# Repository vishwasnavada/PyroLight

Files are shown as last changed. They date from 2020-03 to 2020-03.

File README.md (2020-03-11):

# PyroLight
Automated switch bot for switches using Kemet SS-430 Sensor 

Project Link:
[PyroLight](https://www.hackster.io/vishwasnavada/pyrolight-1d4a31)

##  Initial Protype image
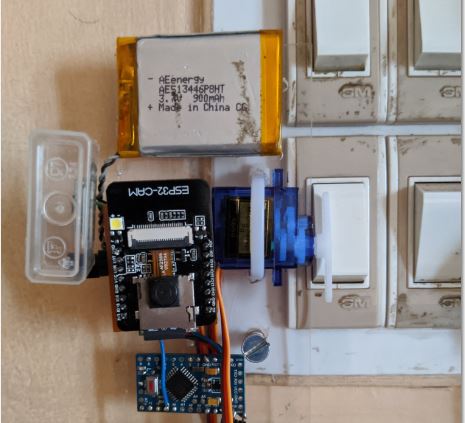
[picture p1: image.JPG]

## Final PCB Version
### Frontside 
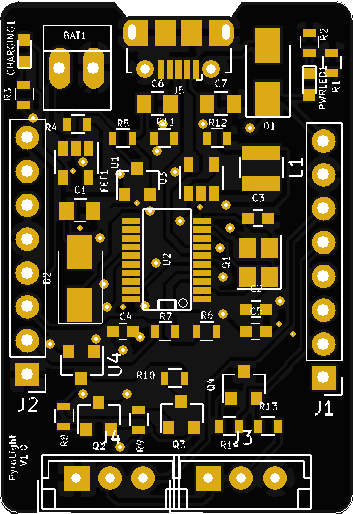
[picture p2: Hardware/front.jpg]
front


### Backside 
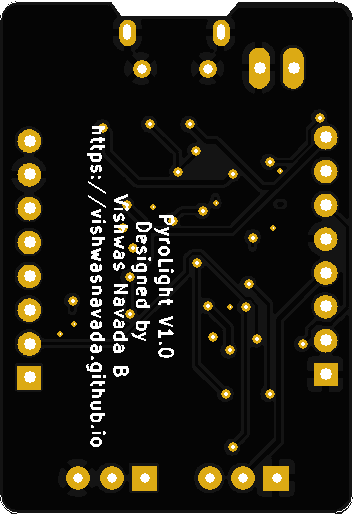
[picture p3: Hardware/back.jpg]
back


### 3D View
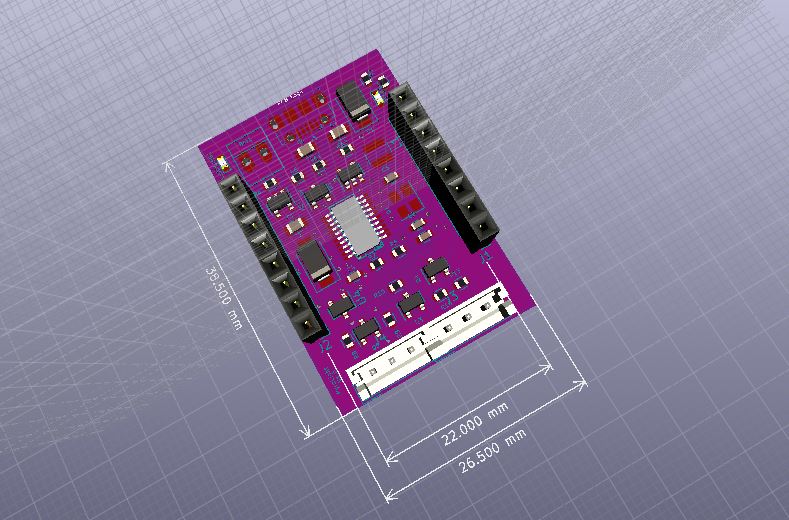
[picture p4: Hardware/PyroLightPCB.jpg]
PyroLightPCB


Here's the video Link:
Watch the video (https://youtu.be/70MHgPO923Y)

I referred schematics from olimex for the esp 32 charging circuit.

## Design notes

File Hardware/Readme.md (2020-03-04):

# Instruction
This folder contains the schematics for the add on board which directly sits on the esp32 Camera board
to program and use it as a normal PyroLight device

## 3D View
PyroLightPCB
### Frontside 
front
### Backside
back

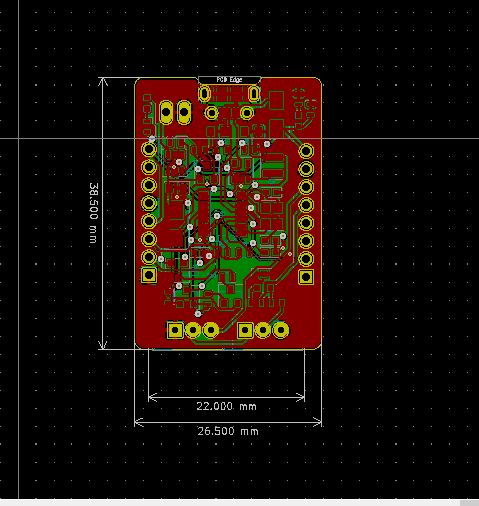
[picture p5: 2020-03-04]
Hardware/PCB.JPG

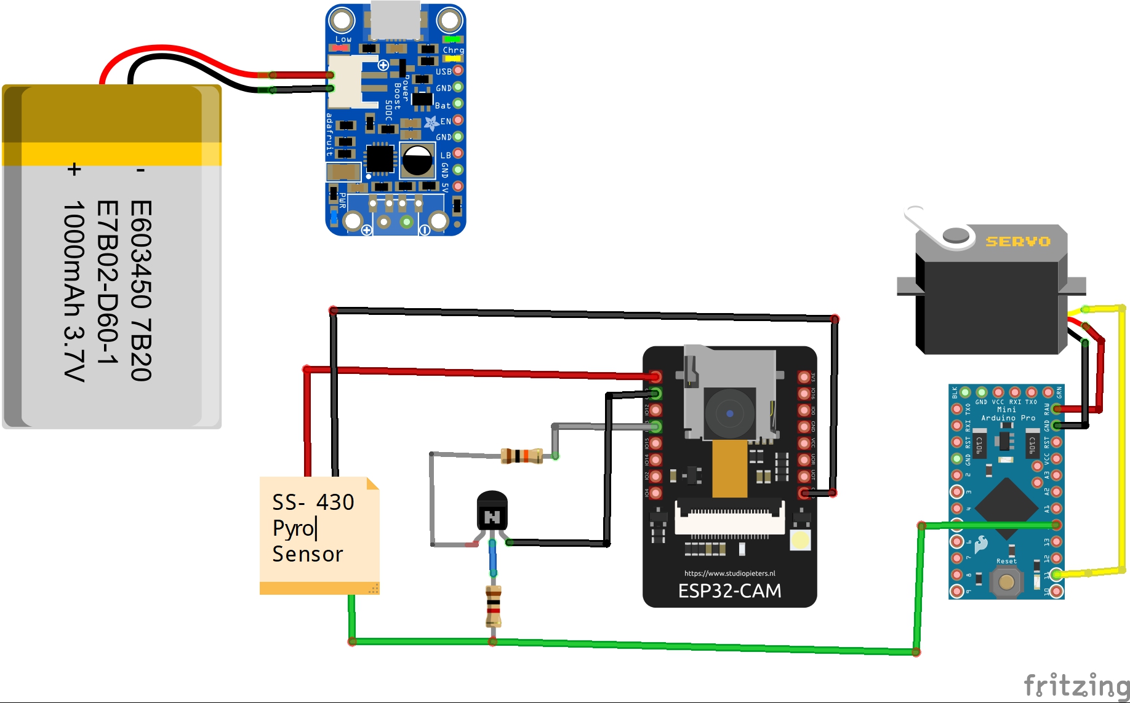
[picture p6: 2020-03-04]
Hardware/schematic.jpg

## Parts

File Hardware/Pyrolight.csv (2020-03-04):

Id | Designator | Package | Quantity | Designation | Supplier and ref
1 | BAT1 | PINHEAD1-2 | 1 | DW02S
2 | C1 | C_0805 | 1 | 47uF/6.3V/
3 | C2 | C_0603 | 1 | 27pF/50V/
4 | C3 | C_0603 | 1 | 27pF/50V
5 | C4 | C_0603 | 1 | 22uF/6.3V/
6 | C5 | C_0603 | 1 | 100nF/50V/
7 | C6,C7 | C_0805 | 2 | 47uF/6.3V/20%/X5R/C0805
8 | CHARGING1 | LED_0603 | 1 | LED/YELLOW/0603
9 | D1,D2 | D_SMA | 2 | 1N5822/SS34/SMA
10 | FET1 | SOT-23 | 1 | WPM2015-3/TR
11 | PWRLED1 | LED_0603 | 1 | LED/RED/0603
12 | Q1 | Crystal_SMD_3225-4pin_3.2x2.5mm | 1 | Q12MHz/20pF/10ppm/4P/3.2x2.5mm
13 | Q2,Q3 | SOT-23 | 2 | BC817-40(SOT23)
14 | Q4 | SOT-23 | 1 | BC547
15 | R1 | R_0603 | 1 | 10k/R0603
16 | R2,R3,R4 | R_0603 | 3 | 2.2k/R0603
17 | R5 | R_0603 | 1 | NA/R0603
18 | R6,R7,R10 | R_0603 | 3 | 220R/R0603
19 | R8,R9 | R_0603 | 2 | 1k/R0603
20 | R11 | R_0603 | 1 | 4.99k/
21 | R12 | R_0603 | 1 | 1.1k/
22 | R13 | R_0603 | 1 | 1k
23 | R14 | R_0603 | 1 | 10k
24 | U1 | SOT-23-5 | 1 | BL4054B-42TPRN(SOT23-5)
25 | U2 | SSOP-20 | 1 | CH340T(SSOP20W)
26 | U3 | SOT-23-5 | 1 | SY8089AAAC(SOT23-5)
27 | J5 | USB_Micro-B_Molex-105017-0001 | 1 | USB_B_Micro
28 | L1 | L_Abracon_ASPI-3012S | 1 | 2.2uH/1.5A/DCR<0.1R/CD32
29 | U4 | SOT-23 | 1 | BAT54C(SOT23-3)
30 | J1,J2 | Socket_Strip_Straight_1x08_Pitch2.54mm | 2 | Conn_01x08_Female
31 | J3 | JST_EH_B03B-EH-A_03x2.50mm_Straight | 1 | SS-430 Proximity sensor
32 | J4 | JST_EH_B03B-EH-A_03x2.50mm_Straight | 1 | Servo

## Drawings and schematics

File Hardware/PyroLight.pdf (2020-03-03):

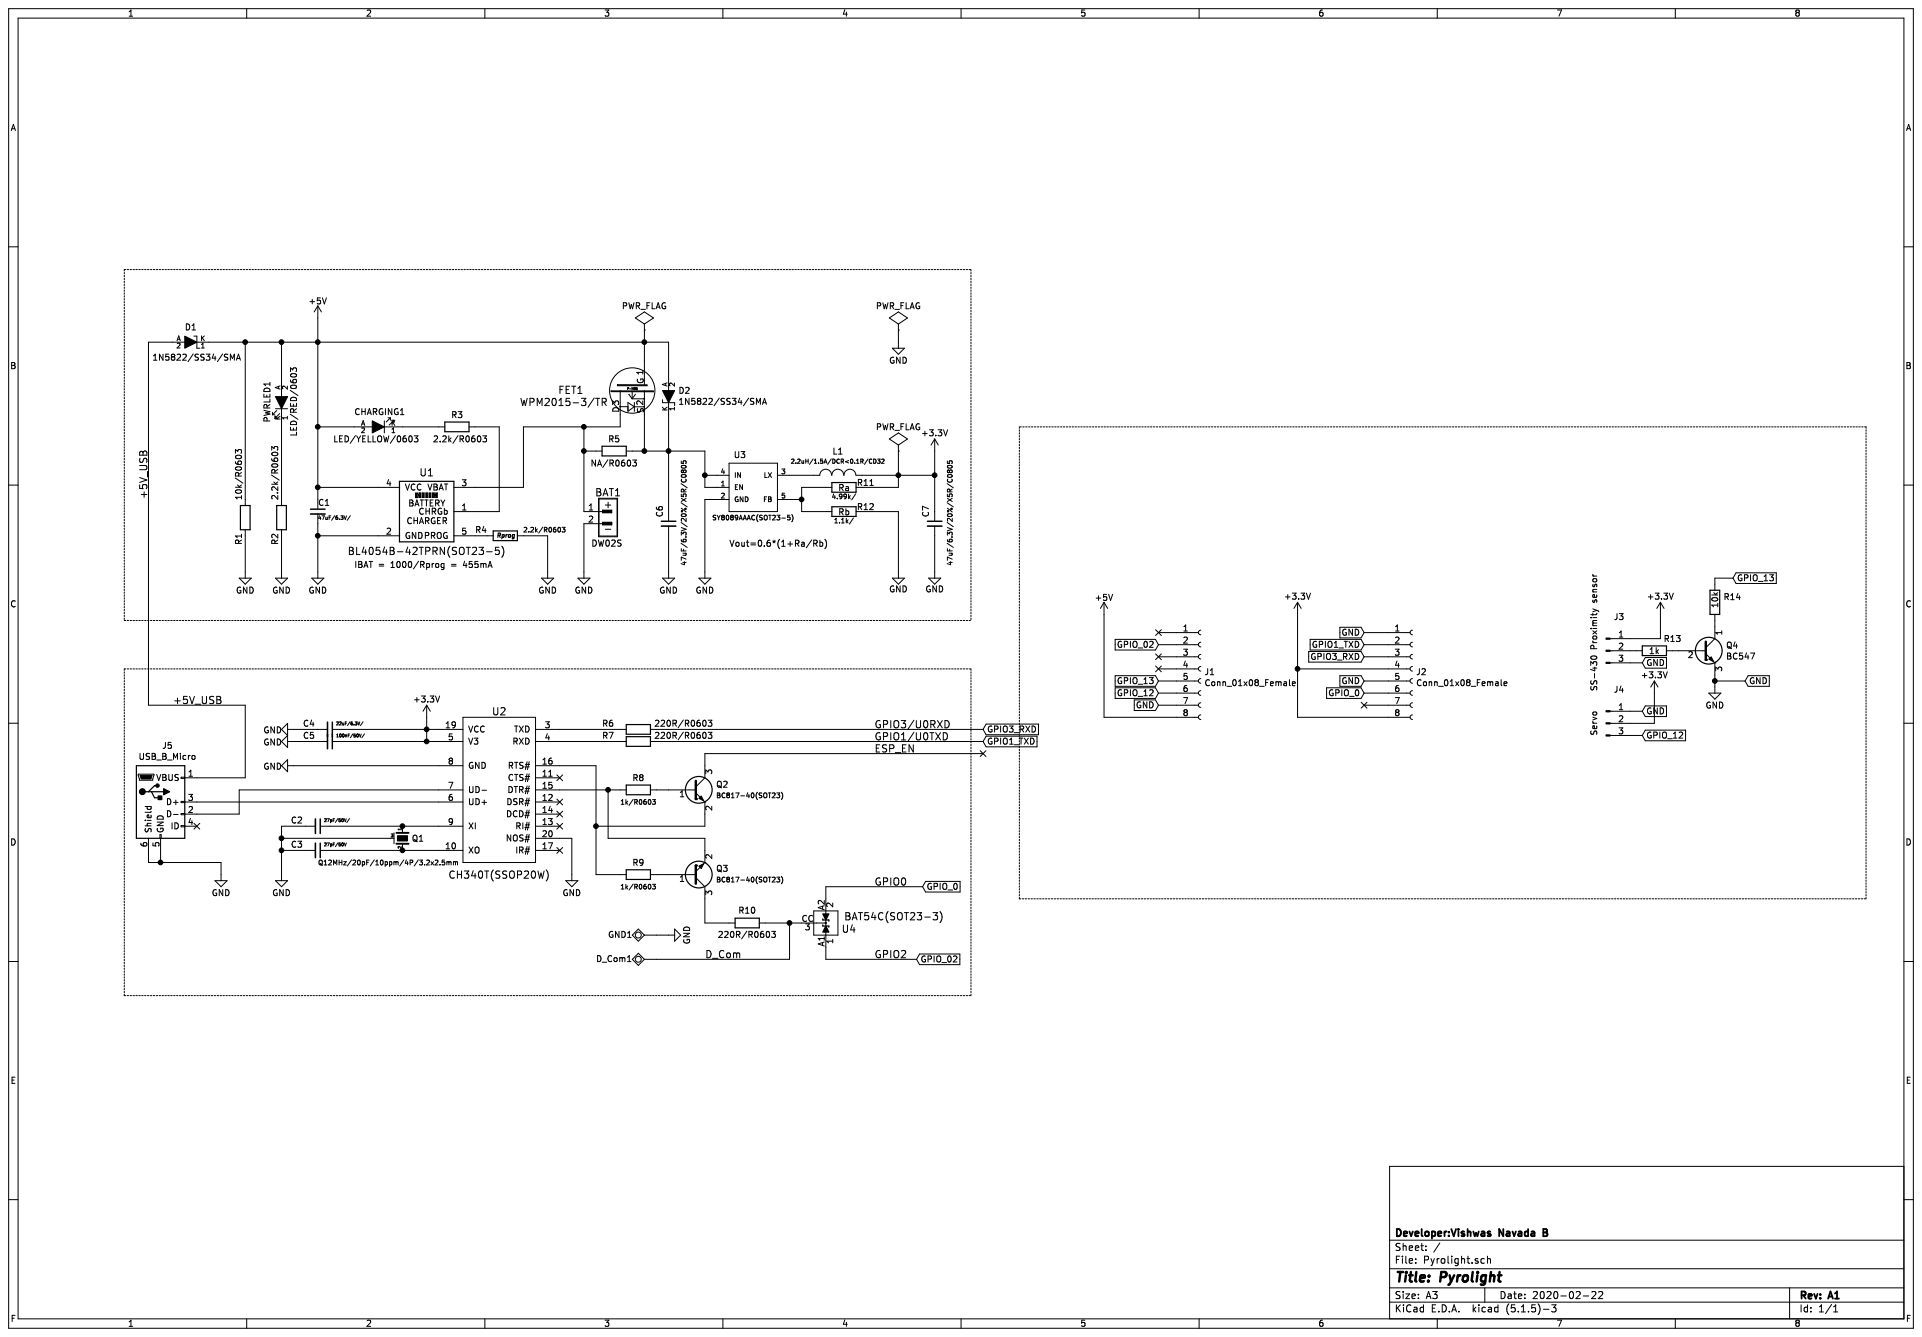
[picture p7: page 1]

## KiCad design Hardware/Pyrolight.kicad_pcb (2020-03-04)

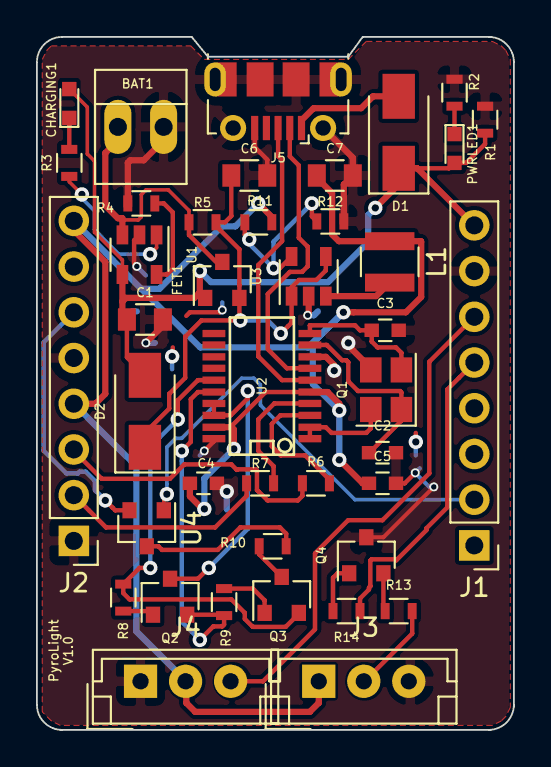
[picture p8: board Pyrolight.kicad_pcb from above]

Board: 2 copper layers, 26.5 x 38.5 mm, 41 parts (0 on the bottom side), 33 nets.

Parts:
BAT1: DW02S; PINHEAD1-2
C1: 47uF/6.3V/; C_0805
C2: 27pF/50V/; C_0603
C3: 27pF/50V; C_0603
C4: 22uF/6.3V/; C_0603
C5: 100nF/50V/; C_0603
C6, C7: 47uF/6.3V/20%/X5R/C0805; C_0805
CHARGING1: LED/YELLOW/0603; LED_0603
D1, D2: 1N5822/SS34/SMA; D_SMA
FET1: WPM2015-3/TR; SOT-23
J1, J2: Conn_01x08_Female; Socket_Strip_Straight_1x08_Pitch2.54mm
J3: SS-430 Proximity sensor; JST_EH_B03B-EH-A_03x2.50mm_Straight
J4: Servo; JST_EH_B03B-EH-A_03x2.50mm_Straight
J5: USB_B_Micro; USB_Micro-B_Molex-105017-0001
L1: 2.2uH/1.5A/DCR<0.1R/CD32; L_Abracon_ASPI-3012S
PWRLED1: LED/RED/0603; LED_0603
Q1: Q12MHz/20pF/10ppm/4P/3.2x2.5mm; Crystal_SMD_3225-4pin_3.2x2.5mm
Q2, Q3: BC817-40(SOT23); SOT-23
Q4: BC547; SOT-23
R1: 10k/R0603; R_0603
R2, R3, R4: 2.2k/R0603; R_0603
R5: NA/R0603; R_0603
R6, R7, R10: 220R/R0603; R_0603
R8, R9: 1k/R0603; R_0603
R11: 4.99k/; R_0603
R12: 1.1k/; R_0603
R13: 1k; R_0603
R14: 10k; R_0603
U1: BL4054B-42TPRN(SOT23-5); SOT-23-5
U2: CH340T(SSOP20W); SSOP-20
U3: SY8089AAAC(SOT23-5); SOT-23-5
U4: BAT54C(SOT23-3); SOT-23

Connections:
+3V3: C4.1, C5.1, C7.1, J2.4, J2.8, J3.1, J4.2, L1.2, R11.2, U2.5, U2.19
+5V: C1.1, CHARGING1.2, D1.1, D2.2, FET1.1, J1.8, PWRLED1.2, R1.1, U1.4
/+5V_USB: D1.2, J5.1
GND: BAT1.2, C1.2, C2.2, C3.2, C4.2, C5.2, C6.2, C7.2, J1.7, J2.1, J2.5, J3.3, J4.1, J5.5, J5.6, Q1.3, Q4.3, R1.2, R2.2, R4.2, R12.2, U1.2, U2.8, U2.20, U3.2
GPIO1_TXD: J2.2, R7.2
GPIO3_RXD: J2.3, R6.2
GPIO_0: J2.6, U4.2
GPIO_02: J1.2, U4.1
GPIO_12: J1.6, J4.3
GPIO_13: J1.5, R14.1
unnamed: BAT1.1, FET1.3, R5.1, U1.3
unnamed: C2.1, Q1.1, U2.9
unnamed: C3.1, Q1.2, U2.10
unnamed: C6.1, D2.1, FET1.2, R5.2, U3.1, U3.4
unnamed: CHARGING1.1, R3.1
unnamed: J3.2, R13.2
unnamed: J5.2, U2.7
unnamed: J5.3, U2.6
unnamed: L1.1, U3.3
unnamed: PWRLED1.1, R2.1
unnamed: Q2.1, R8.2
unnamed: Q2.2, R9.1, U2.16
unnamed: Q3.1, R9.2
unnamed: Q3.2, R8.1, U2.15
unnamed: Q3.3, R10.1
unnamed: Q4.1, R14.2
unnamed: Q4.2, R13.1
unnamed: R3.2, U1.1
unnamed: R4.1, U1.5
unnamed: R6.1, U2.3
unnamed: R7.1, U2.4
unnamed: R10.2, U4.3
unnamed: R11.1, R12.1, U3.5

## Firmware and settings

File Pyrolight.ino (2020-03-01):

/* I would like to thank open source community and websites like hackster.io, instructables and randomnerdtutorials for the resources on ESP32 camera*/ 
#include "esp_camera.h"
#include "FS.h"
#include "SPI.h"
#include "SD.h"
#include "EEPROM.h"
#include "driver/rtc_io.h"
#include "ESP32_MailClient.h"
#include "soc/soc.h"
#include "soc/rtc_cntl_reg.h"

// Select camera model
//#define CAMERA_MODEL_WROVER_KIT
//#define CAMERA_MODEL_ESP_EYE
//#define CAMERA_MODEL_M5STACK_PSRAM
//#define CAMERA_MODEL_M5STACK_WIDE
#define CAMERA_MODEL_AI_THINKER

#include "camera_pins.h"

#define ID_ADDRESS            0x00
#define COUNT_ADDRESS         0x01
#define ID_BYTE               0xAA
#define EEPROM_SIZE           0x0F

uint16_t nextImageNumber = 0;

#define WIFI_SSID             "SSID"
#define WIFI_PASSWORD         "pswd"

#define emailSenderAccount    "email"
#define emailSenderPassword   "password"

#define emailRecipient        "recipient@email.com"
//#define emailRecipient2     "recipient2@email.com"

//The Email Sending data object contains config and data to send
SMTPData smtpData;

//Callback function to get the Email sending status
void sendCallback(SendStatus info);

// Arduino like ServoWrite
// value has to be between 0 and valueMax
void ledcAnalogWrite(uint8_t channel, uint32_t value, uint32_t valueMax = 180) {
  // calculate duty, 8191 from 2 ^ 13 - 1
  uint32_t duty = (8191 / valueMax) * min(value, valueMax);
  ledcWrite(channel, duty);

}

void setup() {
  WRITE_PERI_REG(RTC_CNTL_BROWN_OUT_REG, 0); //disable brownout detector
  Serial.begin(115200);
  Serial.println();
  Serial.println("Booting...");
  int  i = 0;
  pinMode(4, INPUT);              //Since I do not want to use flash I'm disbling this
  digitalWrite(4, LOW);
  rtc_gpio_hold_dis(GPIO_NUM_4);  //diable pin hold if it was enabled before sleeping
  ledcSetup(2, 50, 16); //channel, freq, resolution
  ledcAttachPin(2, 2); // pin, channel
  int onValue = 180; //Set this servo pin angles based on switch requirements
  int offValue = 150; //Set this servo pin angles based on switch requirements
  if (i == 0)
  {
    ledcAnalogWrite(2, onValue);
    i = 1;
  }
  if (i == 1)
  {
    ledcAnalogWrite(2, offValue);
    i = 0;
  }

  //connect to WiFi network
  Serial.print("Connecting to AP");
  WiFi.begin(WIFI_SSID, WIFI_PASSWORD);
  while (WiFi.status() != WL_CONNECTED)
  {
    Serial.print(".");
    delay(200);
  }

  Serial.println("");
  Serial.println("WiFi connected.");
  Serial.println("IP address: ");
  Serial.println(WiFi.localIP());
  Serial.println();

  camera_config_t config;
  config.ledc_channel = LEDC_CHANNEL_0;
  config.ledc_timer = LEDC_TIMER_0;
  config.pin_d0 = Y2_GPIO_NUM;
  config.pin_d1 = Y3_GPIO_NUM;
  config.pin_d2 = Y4_GPIO_NUM;
  config.pin_d3 = Y5_GPIO_NUM;
  config.pin_d4 = Y6_GPIO_NUM;
  config.pin_d5 = Y7_GPIO_NUM;
  config.pin_d6 = Y8_GPIO_NUM;
  config.pin_d7 = Y9_GPIO_NUM;
  config.pin_xclk = XCLK_GPIO_NUM;
  config.pin_pclk = PCLK_GPIO_NUM;
  config.pin_vsync = VSYNC_GPIO_NUM;
  config.pin_href = HREF_GPIO_NUM;
  config.pin_sscb_sda = SIOD_GPIO_NUM;
  config.pin_sscb_scl = SIOC_GPIO_NUM;
  config.pin_pwdn = PWDN_GPIO_NUM;
  config.pin_reset = RESET_GPIO_NUM;
  config.xclk_freq_hz = 20000000;
  config.pixel_format = PIXFORMAT_JPEG;

  //init with high specs to pre-allocate larger buffers
  if (psramFound())
  {
    config.frame_size = FRAMESIZE_UXGA;
    config.jpeg_quality = 10;
    config.fb_count = 2;
  } else
  {
    config.frame_size = FRAMESIZE_SVGA;
    config.jpeg_quality = 12;
    config.fb_count = 1;
  }


  //initialize camera
  esp_err_t err = esp_camera_init(&config);
  if (err != ESP_OK)
  {
    Serial.printf("Camera init failed with error 0x%x", err);
    return;
  }

  //set the camera parameters
  sensor_t * s = esp_camera_sensor_get();
  s->set_contrast(s, 2);    //min=-2, max=2
  s->set_brightness(s, 2);  //min=-2, max=2
  s->set_saturation(s, 2);  //min=-2, max=2
  delay(100);               //wait a little for settings to take effect

  //mount SD card
  Serial.println("Mounting SD Card...");
  MailClient.sdBegin(14, 2, 15, 13);

  if (!SD.begin())
  {
    Serial.println("Card Mount Failed");
    return;
  }

  //initialize EEPROM & get file number
  if (!EEPROM.begin(EEPROM_SIZE))
  {
    Serial.println("Failed to initialise EEPROM");
    Serial.println("Exiting now");
    while (1);  //wait here as something is not right
  }


  if (EEPROM.read(ID_ADDRESS) != ID_BYTE)   //there will not be a valid picture number
  {
    Serial.println("Initializing ID byte & restarting picture count");
    nextImageNumber = 0;
    EEPROM.write(ID_ADDRESS, ID_BYTE);
    EEPROM.commit();
  }
  else                                      //obtain next picture number
  {
    EEPROM.get(COUNT_ADDRESS, nextImageNumber);
    nextImageNumber +=  1;
    Serial.print("Next image number:");
    Serial.println(nextImageNumber);
  }

  //take new image
  camera_fb_t * fb = NULL;

  //obtain camera frame buffer
  fb = esp_camera_fb_get();
  if (!fb)
  {
    Serial.println("Camera capture failed");
    Serial.println("Exiting now");
    while (1);  //wait here as something is not right
  }

  //save to SD card
  //generate file path
  String path = "/IMG" + String(nextImageNumber) + ".jpg";

  fs::FS &fs = SD;

  //create new file
  File file = fs.open(path.c_str(), FILE_WRITE);
  if (!file)
  {
    Serial.println("Failed to create file");
    Serial.println("Exiting now");
    while (1);  //wait here as something is not right
  }
  else
  {
    file.write(fb->buf, fb->len);
    EEPROM.put(COUNT_ADDRESS, nextImageNumber);
    EEPROM.commit();
  }
  file.close();

  //return camera frame buffer
  esp_camera_fb_return(fb);
  Serial.printf("Image saved: %s\n", path.c_str());

  //send email
  Serial.println("Sending email...");
  //Set the Email host, port, account and password
  smtpData.setLogin("smtp.gmail.com", 587, emailSenderAccount, emailSenderPassword);

  //Set the sender name and Email
  smtpData.setSender("PyroLight", emailSenderAccount);

  //Set Email priority or importance High, Normal, Low or 1 to 5 (1 is highest)
  smtpData.setPriority("Normal");

  //Set the subject
  smtpData.setSubject("Motion Detected - by PyroLight");

  //Set the message - normal text or html format
  smtpData.setMessage("<div style=\"color:#003366;font-size:20px;\">Image captured and attached.</div>", true);

  //Add recipients, can add more than one recipient
  smtpData.addRecipient(emailRecipient);
  //smtpData.addRecipient(emailRecipient2);

  //Add attach files from SD card
  smtpData.addAttachFile(path);

  //Set the storage types to read the attach files (SD is default)
  smtpData.setFileStorageType(MailClientStorageType::SD);

  smtpData.setSendCallback(sendCallback);

  //Start sending Email, can be set callback function to track the status
  if (!MailClient.sendMail(smtpData))
    Serial.println("Error sending Email, " + MailClient.smtpErrorReason());

  //Clear all data from Email object to free memory
  smtpData.empty();

  pinMode(4, OUTPUT);              //GPIO for LED flash
  digitalWrite(4, LOW);            //turn OFF flash LED
  rtc_gpio_hold_en(GPIO_NUM_4);    //make sure flash is held LOW in sleep
  Serial.println("Entering deep sleep mode");
  Serial.flush();
  esp_sleep_enable_ext0_wakeup(GPIO_NUM_13, 0);   //wake up when pin 13 goes LOW
  delay(5000);                                   //wait for 5 seconds to reduce false triggers from SS-430.
  esp_deep_sleep_start();
}

void loop()
{


}

//Callback function to get the Email sending status
void sendCallback(SendStatus msg)
{
  //Print the current status
  Serial.println(msg.info());

  //Do something when complete
  if (msg.success())
  {
    Serial.println("----------------");
  }
}

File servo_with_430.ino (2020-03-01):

#include <Servo.h>

Servo myservo;
int pos = 150;
const byte LED = 13;
int pin = A0;
int i = 0;
unsigned long dur = 0;
int found = LOW;
void setup()
{
  myservo.attach(11);
  Serial.begin(9600);
  pinMode(LED, OUTPUT);
  pinMode(A0, INPUT);
  
     myservo.write(pos);
}
void loop()
{ 
  while (i < 3)
  {
    dur = pulseIn(pin, HIGH,700000);
    if (dur > 300000)
    {
      i++;
    }
  }
  if (found == HIGH)
  {
    found = LOW;
    myservo.write(150);
    digitalWrite(LED, LOW);
  }
  else
  {
    found = HIGH;
    myservo.write(180);
    digitalWrite(LED, HIGH);
  }
  dur = 0;
  i = 0;
  delay(1000);
}

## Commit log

2020-03-03 Updated Schematics
2020-03-03 Updates schematics
    [Pyrolight.sch]
2020-03-04 added Gerbers
2020-03-04 Added gerbers
2020-03-04 Gerber files
    [Pyrolight-B_Cu.gbr, Pyrolight-B_Mask.gbr, Pyrolight-B_Paste.gbr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]
2020-03-04 Added other project files
    [Pyrolight.csv, Pyrolight.kicad_pcb, Pyrolight.sch]
